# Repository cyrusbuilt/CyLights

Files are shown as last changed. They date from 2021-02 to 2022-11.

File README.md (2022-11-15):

# CyLights



IoT Integration Control Board and Firmware for remote controlled 5-outlet system.

## Synopsis

This system was designed to integrate with the [Etekcity Zap 5-Channel Wireless Outlet Switch System](https://www.etekcity.com/product/100068) and make it controllable via software.  I originally bought the Etekcity kit so that I could turn lamps on/off using the remote in my old apartment. I quickly realized it wouldn't be difficult to modify the remote so that I could integrate it into a home automation system. So this repo contains the design files for the board, sources for the firmware, and [OpenHAB](https://www.openhab.org/) integration files. CyLights uses an [ESP8266](https://www.adafruit.com/product/2471) at it's core, and basically just uses the remote that comes with the Etekcity kit as a transmitter, making the whole thing wireless (with the exception of the power supply) so you can place it anywhere that is in range of all your wireless outlets AND your WiFi router.

## Disclaimer

CyLights requires you to remove the battery and modify the remote that comes with the Etekcity kit. I am not liable for any damage you may cause to your controller (or any other hardware for that matter) should you attempt to do this.  Also, while I am currently using this system daily, it is still a work in progress and not yet production-ready and documentation is incomplete. If you are interested in this project, check back soon!

## I'm not a n00b, get on with it!

Ok, fair enough. Consider this a quick start guide then:

1) Review the schematics and BOM in the ```schematics``` folder.

2) Send the gerbers off to your preferred PCB fab house to get the boards made, then gather up the necessary components in the BOM. I also recommend 12 female dupont cables and a 12VDC @ 1.0A power supply and 2 TO-220 heat sinks (along with thermal paste).

3) Assemble the CyLights board, then remove the battery from the Etekcity remote and disassemble it (it only has 2 small phillips head screws).

4) Cut one end off each dupont cable, strip a small amount of insulation off each one and solder each lead to the inside contact of each button and one lead each to the battery terminals on the remote (guide coming soon).

5) Connect each dupont cable to the appropriate pins on pin header J2 on the CyLights board.

6) Connect 12VDC power supply to screw terminal block J1 on the CyLights board.

7) Connect the CyLights board to your computer using an FTDI cable and put the ESP8266 in program mode.

8) Build and flash the firmware to the MCU. Then place the MCU back into program mode again. Then edit the config.json file in the ```data``` folder with the appropriate values, then upload the filesystem image. Then reset the MCU and go into monitor mode so you can see the serial output.

9) If successful, you should be able to see the CyLights board boot correctly and connect to your WiFi. If you already have an MQTT broker set up on your network and you set the appropriate parameters in the config file, it should also successfully connect to the broker and publish its first status message.

10) If you already have OpenHAB setup somewhere on your network, you can copy the files in the ```openhab``` folder to their appropriate locations (and modify as needed) and you should be able to monitor and control the system from OpenHab via the "CyLights" sitemap.

Tada! At this point, if all is well then you can unplug the FTDI cable (unless you want to continue to monitor the serial output or access the built-in configuration and control menu) and mount or install the boards wherever/however you want. I personally mounted the whole thing in an ABS plastic box for the time being, but I intend to mount it in a custom panel along with a bunch of other gear once our new house is done being built.

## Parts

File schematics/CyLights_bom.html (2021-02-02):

Label | Part Type | Properties
C1 | Ceramic Capacitor | voltage 6.3V; package 100 mil [THT, multilayer]; capacitance 0.1mF
C2 | Ceramic Capacitor | voltage 6.3V; package 100 mil [THT, multilayer]; capacitance 0.1mF
C3 | Electrolytic Capacitor | voltage 6.3V; package 100 mil [THT, electrolytic]; capacitance 0.22mF
C4 | Ceramic Capacitor | voltage 6.3V; package 100 mil [THT, multilayer]; capacitance 0.47mF
C5 | Tantalum Capacitor | voltage 6.3V; package 100 mil [THT, tantalum]; capacitance 1μF
C6 | Ceramic Capacitor | voltage 6.3V; package 100 mil [THT, multilayer]; capacitance 0.1mF
Huzzah ESP8266 | Adafruit HUZZAH ESP8266 | variant variant 2; part # Adafruit #2471
IC1 | Voltage Regulator | variant variant 1; chip LM2940CT; voltage 9V; package to-220-alt
IC2 | Voltage Regulator | variant side; chip 78005; voltage 5V; package 78xxl
IC3 | MCP23017 I2C I/O Expander | variant PDIP
J1 | Screw terminal - 2 pins | pins 2; package THT; hole size 1.0mm,0.508mm; pin spacing 0.137in (3.5mm)
J2 | Generic male header - 12 pins | pins 12; form ♂ (male); row single; package THT; hole size 1.0mm,0.508mm; pin spacing 0.1in (2.54mm)
J3 | Generic male header - 6 pins | pins 6; form ♂ (male); row single; package THT; hole size 1.0mm,0.508mm; pin spacing 0.1in (2.54mm)
LED1 | Red (635nm) LED | leg yes; package 5 mm [THT]; color Red (635nm)
LED2 | Green (570nm) LED | leg yes; package 3 mm [THT]; color Green (570nm)
LED3 | Green (570nm) LED | leg yes; package 3 mm [THT]; color Green (570nm)
LED4 | Green (570nm) LED | leg yes; package 3 mm [THT]; color Green (570nm)
LED5 | Green (570nm) LED | leg yes; package 3 mm [THT]; color Green (570nm)
LED6 | Green (570nm) LED | leg yes; package 3 mm [THT]; color Green (570nm)
LED7 | Yellow (595nm) LED | leg yes; package 5 mm [THT]; color Yellow (595nm)
Part1 | Schematic Frame | project CyLights; descr CyLights IoT Control Board; rev 1.5; sheet 1/1; date 1563226096; filename CyLights.fzz
R1 | 4.7kΩ Resistor | resistance 4.7kΩ; bands 4; package THT; pin spacing 400 mil; tolerance ±5%
R2 | 150Ω Resistor | resistance 150Ω; bands 4; package THT; pin spacing 400 mil; tolerance ±5%
U1 | AQW214 | variant variant 1; chip label AQW214; pins 8; editable pin labels false; package DIP (Dual Inline) [THT]; pin spacing 300mil
U2 | AQW214 | variant variant 1; chip label AQW214; pins 8; editable pin labels false; package DIP (Dual Inline) [THT]; pin spacing 300mil
U3 | AQW214 | variant variant 1; chip label AQW214; pins 8; editable pin labels false; package DIP (Dual Inline) [THT]; pin spacing 300mil
U4 | AQW214 | variant variant 1; chip label AQW214; pins 8; editable pin labels false; package DIP (Dual Inline) [THT]; pin spacing 300mil
U5 | AQW214 | variant variant 1; chip label AQW214; pins 8; editable pin labels false; package DIP (Dual Inline) [THT]; pin spacing 300mil
Amount | Part Type | Properties
3 | Ceramic Capacitor | voltage 6.3V; package 100 mil [THT, multilayer]; capacitance 0.1mF
1 | Electrolytic Capacitor | voltage 6.3V; package 100 mil [THT, electrolytic]; capacitance 0.22mF
1 | Ceramic Capacitor | voltage 6.3V; package 100 mil [THT, multilayer]; capacitance 0.47mF
1 | Tantalum Capacitor | voltage 6.3V; package 100 mil [THT, tantalum]; capacitance 1μF
1 | Adafruit HUZZAH ESP8266 | variant variant 2; part # Adafruit #2471
1 | Voltage Regulator | variant variant 1; chip LM2940CT; voltage 9V; package to-220-alt
1 | Voltage Regulator | variant side; chip 78005; voltage 5V; package 78xxl
1 | MCP23017 I2C I/O Expander | variant PDIP
1 | Screw terminal - 2 pins | pins 2; package THT; hole size 1.0mm,0.508mm; pin spacing 0.137in (3.5mm)
1 | Generic male header - 12 pins | pins 12; form ♂ (male); row single; package THT; hole size 1.0mm,0.508mm; pin spacing 0.1in (2.54mm)
1 | Generic male header - 6 pins | pins 6; form ♂ (male); row single; package THT; hole size 1.0mm,0.508mm; pin spacing 0.1in (2.54mm)
1 | Red (635nm) LED | leg yes; package 5 mm [THT]; color Red (635nm)
5 | Green (570nm) LED | leg yes; package 3 mm [THT]; color Green (570nm)
1 | Yellow (595nm) LED | leg yes; package 5 mm [THT]; color Yellow (595nm)
1 | Schematic Frame | project CyLights; descr CyLights IoT Control Board; rev 1.5; sheet 1/1; date 1563226096; filename CyLights.fzz
1 | 4.7kΩ Resistor | resistance 4.7kΩ; bands 4; package THT; pin spacing 400 mil; tolerance ±5%
1 | 150Ω Resistor | resistance 150Ω; bands 4; package THT; pin spacing 400 mil; tolerance ±5%
5 | AQW214 | variant variant 1; chip label AQW214; pins 8; editable pin labels false; package DIP (Dual Inline) [THT]; pin spacing 300mil

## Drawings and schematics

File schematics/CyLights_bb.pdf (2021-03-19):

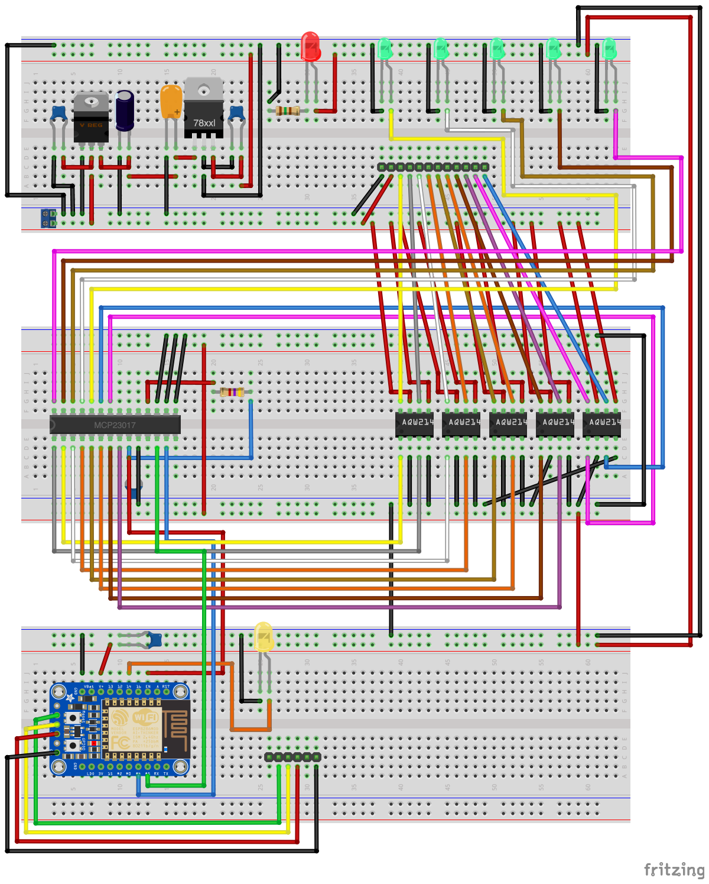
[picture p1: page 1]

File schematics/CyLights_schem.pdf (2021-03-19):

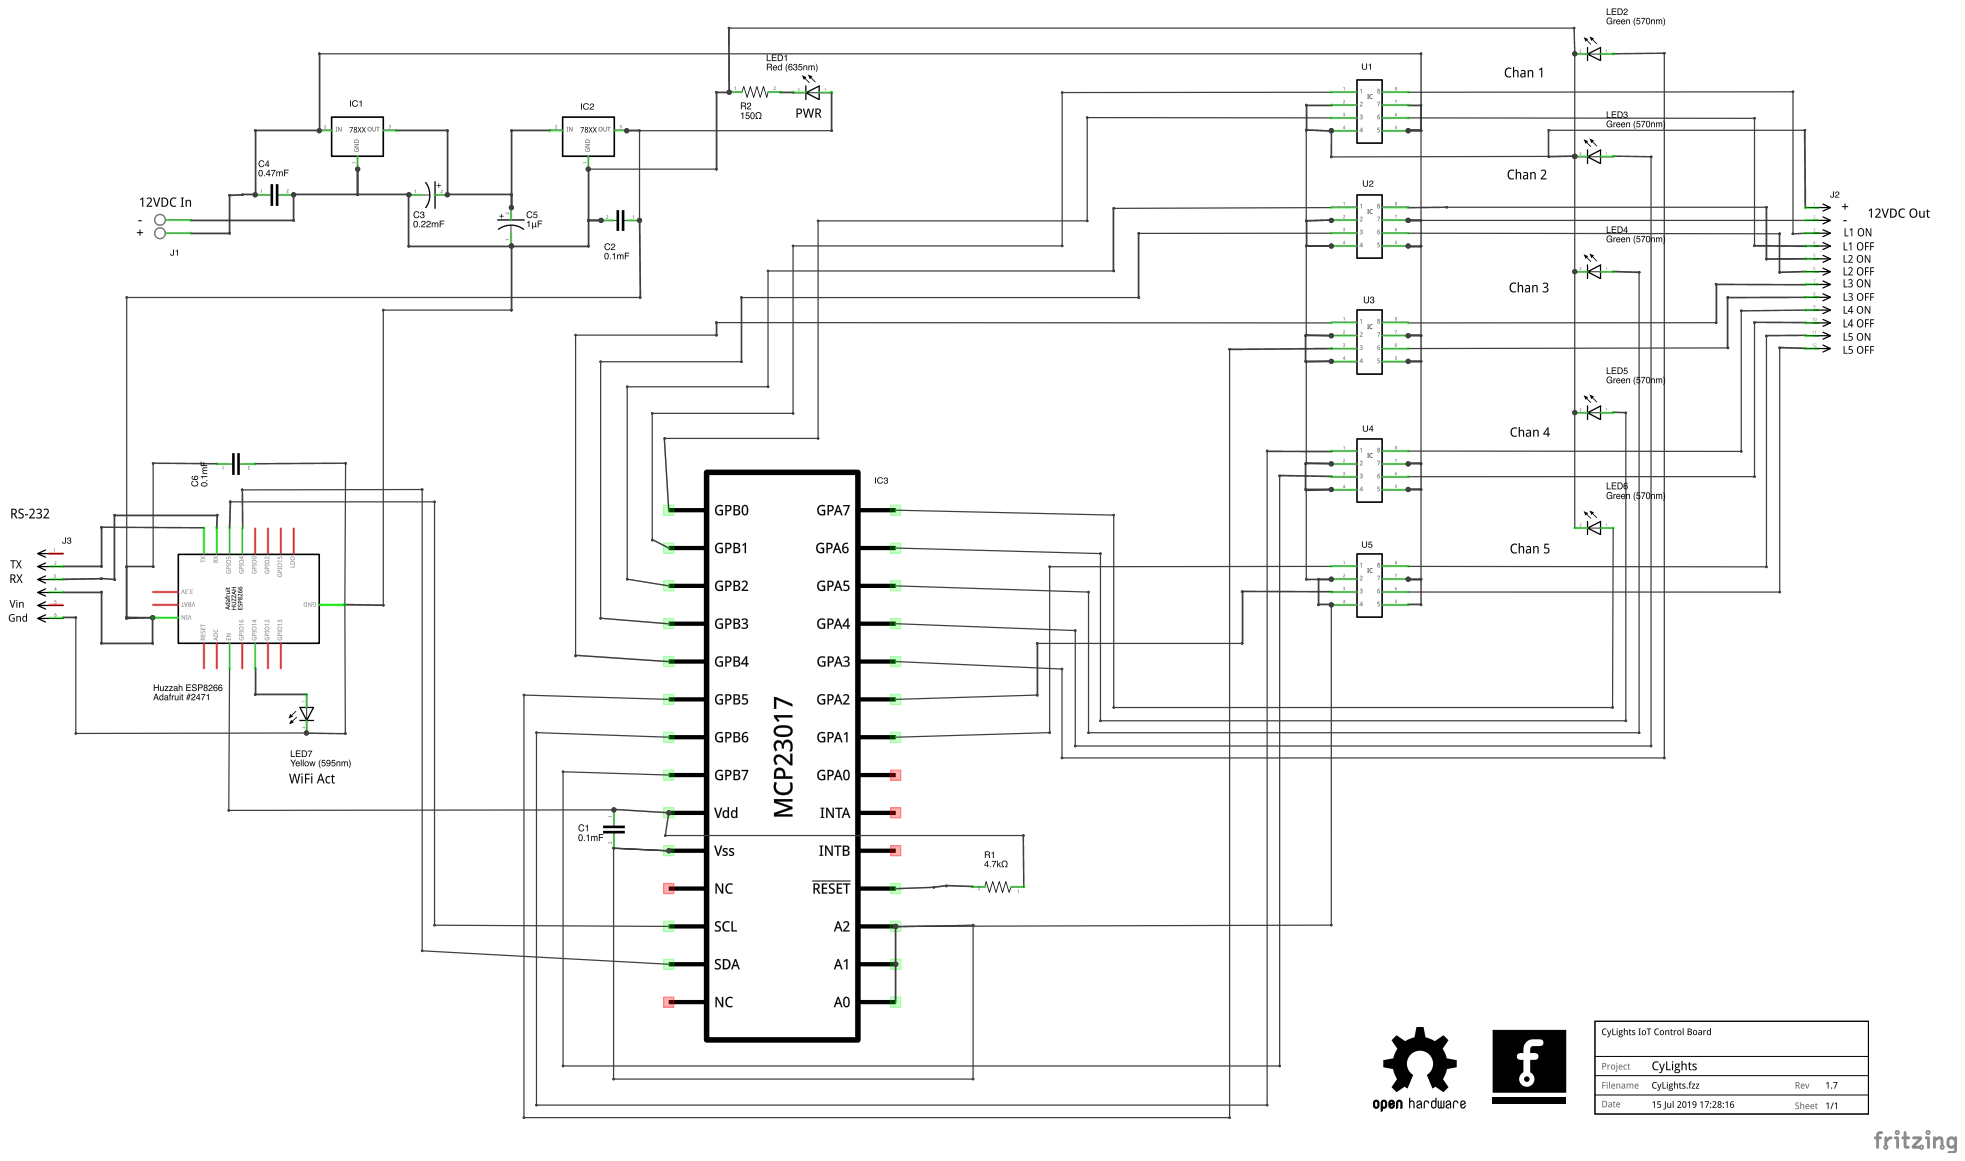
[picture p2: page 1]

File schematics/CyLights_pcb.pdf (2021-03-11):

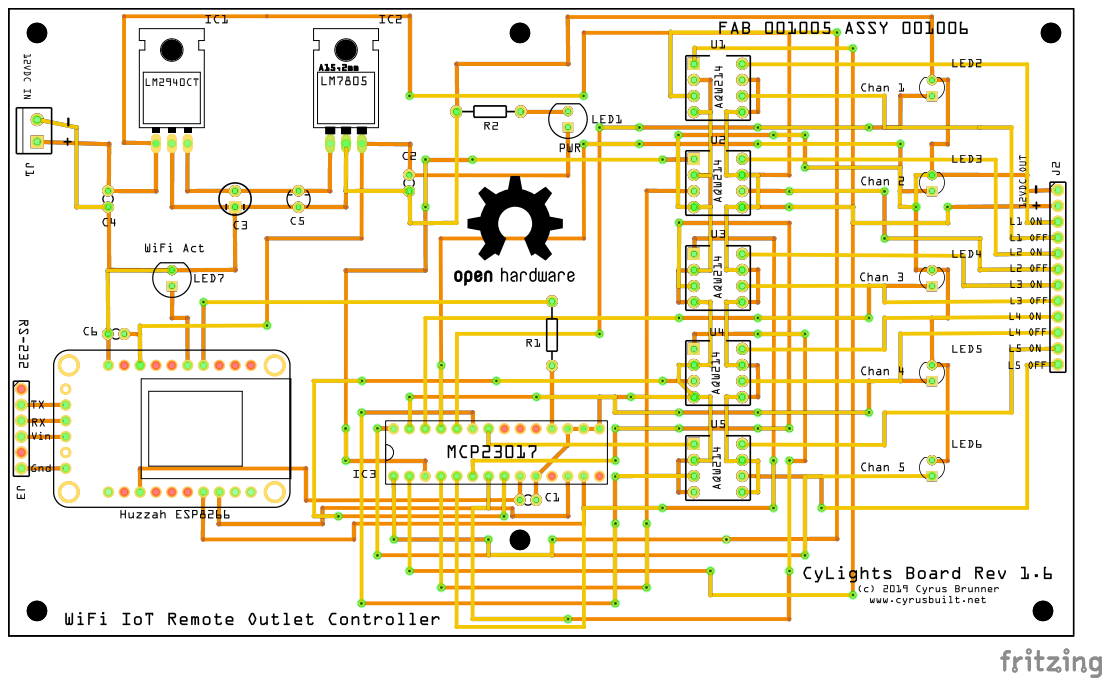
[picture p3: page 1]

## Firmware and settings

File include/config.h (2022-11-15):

#ifndef config_h
#define config_h

#include <IPAddress.h>

// Configuration
#define DEBUG                                   // Uncomment to enable additional debug info.
#define DEVICE_NAME "CYLIGHTS"                  // The device name.
#define DEVICE_CLASS "cylights"                 // The device class (used for discovery).
#define ENABLE_OTA                              // Comment this line to disable OTA updates.
#define ENABLE_MDNS                             // Comment this line to disable the MDNS.
#define DEFAULT_SSID "your_ssid_here"           // Put the SSID of your WiFi here.
#define DEFAULT_PASSWORD "your_password_here"   // Put your WiFi password here.
#define CLOCK_TIMEZONE -4                       // The timezone this device is located in. (For example, EST when observing DST = GMT-4, when not = GMT-5)
#define SERIAL_BAUD 115200                      // The BAUD rate (speed) of the serial port (console).
#define CONFIG_FILE_PATH "/config.json"         // The path to the config file in SPIFFS.
#define CHECK_WIFI_INTERVAL 60000               // How often to check WiFi status (milliseconds).
#define CHECK_MQTT_INTERVAL 120000               // How often to check connectivity to the MQTT broker.
#define CLOCK_SYNC_INTERVAL 3600000             // How often to sync the local clock with NTP (milliseconds).
#define MQTT_TOPIC_STATUS "cylights/status"     // The MQTT topic to publish status messages to.
#define MQTT_TOPIC_CONTROL "cylights/control"   // The MQTT topic to subscribe to for control messages.
#define MQTT_TOPIC_DISCOVERY "redqueen/config"  // The MQTT topic to publish discovery packets to.
#define BUTTON_PULSE_DELAY 1000                 // How long to pulse an on/off button.
#define MQTT_BROKER "your_mqtt_host_here"       // The host name or IP of the MQTT broker to connect to.
#define MQTT_PORT 1883                          // The MQTT port to connect on (default is 1883).
#ifdef ENABLE_OTA
    #include <ArduinoOTA.h>
    #define OTA_HOST_PORT 8266                     // The OTA updater port.
    #define OTA_PASSWORD "your_ota_password_here"  // The OTA updater password.
#endif
IPAddress defaultIp(192, 168, 0, 220);                 // The default static host IP.
IPAddress defaultGw(192, 168, 0, 1);                   // The default static gateway IP.
IPAddress defaultSm(255, 255, 255, 0);                 // The default static subnet mask.
IPAddress defaultDns(defaultGw);

typedef struct {
    // Network stuff
    String hostname;
    String ssid;
    String password;
    IPAddress ip;
    IPAddress gw;
    IPAddress sm;
    IPAddress dns;
    bool useDhcp;

    uint8_t clockTimezone;

    // MQTT stuff
    String mqttTopicStatus;
    String mqttTopicControl;
    String mqttTopicDiscovery;
    String mqttBroker;
    String mqttUsername;
    String mqttPassword;
    uint16_t mqttPort;

    // OTA stuff
    uint16_t otaPort;
    String otaPassword;
} config_t;

#endif

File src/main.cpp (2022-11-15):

/**
 * @file main.cpp
 * @author Chris (Cyrus) Brunner (cyrusbuilt at gmail dot com)
 * 
 * @brief CyLights Firmware
 * This is the firmware for CyLights, an IoT integration system designed to
 * be used with a modified version of the Etekcity 5-outlet remote control
 * system. CyLights is meant to essentially convert the remote control into
 * an RF transmitter peripheral which is then powered and controlled by CyLights
 * itself and can then be controlled over MQTT and can be integrated with
 * home automation systems such as OpenHab.
 * 
 * @version 1.3
 * @copyright Copyright (c) Cyrus Brunner 2022
 */

#ifndef ESP8266
    #error This firmware is only compatible with ESP8266 controllers.
#endif

#include <Arduino.h>
#include <ESP8266WiFi.h>
#include <FS.h>
#include <WiFiClient.h>
#include <Wire.h>
#include <time.h>
#include <TZ.h>
#include "config.h"
#include "Adafruit_MCP23017.h"
#include "TelemetryHelper.h"
#include "LED.h"
#include "Relay.h"
#include "PubSubClient.h"
#include "TaskScheduler.h"
#include "ResetManager.h"
#include "ESPCrashMonitor.h"
#include "ArduinoJson.h"
#include "LightController.h"
#include "Console.h"

#define VERSION "1.3"

#define PRIMARY_I2C_ADDRESS 0
#define I2C_ADDRESS_OFFSET 32

// Pin definitions
#define PIN_ACT_LED 14
#define PIN_BUS_RESET 16

// Forward declarations
void onCheckWiFi();
void onCheckMqtt();
void failSafe();
void onMqttMessage(char* topic, byte* payload, unsigned int length);
void onSyncClock();

// Global vars
#ifdef ENABLE_MDNS
    #include <ESP8266mDNS.h>
    MDNSResponder mdns;
#endif
WiFiClient wifiClient;
PubSubClient mqttClient(wifiClient);
LED actLED(PIN_ACT_LED, NULL);
Task tCheckWifi(CHECK_WIFI_INTERVAL, TASK_FOREVER, &onCheckWiFi);
Task tCheckMqtt(CHECK_MQTT_INTERVAL, TASK_FOREVER, &onCheckMqtt);
Task tSyncClock(CLOCK_SYNC_INTERVAL, TASK_FOREVER, &onSyncClock);
Scheduler taskMan;
Adafruit_MCP23017 bus;
LightController controller(&bus);
config_t config;
bool filesystemMounted = false;
bool primaryExpanderFound = false;
volatile SystemState sysState = SystemState::BOOTING;

/**
 * @brief Get the Current Time object
 * 
 * @return String 
 */
String getCurrentTime() {
    time_t now = time(nullptr);
    struct tm *timeinfo = localtime(&now);
    String result = String(asctime(timeinfo));
    result.replace("\n", "");
    return result;
}

/**
 * @brief Synchronize the local system clock via NTP. Note: This does not take DST
 * into account. Currently, you will have to adjust the CLOCK_TIMEZONE define
 * manually to account for DST when needed.
 */
void onSyncClock() {
    configTime(TZ_America_New_York, "pool.ntp.org");
    Serial.print(F("INIT: Waiting for NTP time sync..."));
    delay(500);
    while (!time(nullptr)) {
        ESPCrashMonitor.iAmAlive();
        Serial.print(F("."));
        delay(500);
    }

    Serial.println(F("DONE"));
    Serial.print(F("INFO: Current time: "));
    Serial.println(getCurrentTime());
}

/**
 * @brief Publishes the system's current state to the configured status topic.
 */
void publishSystemState() {
    if (mqttClient.connected()) {
        actLED.on();
        uint16_t freeMem = ESP.getMaxFreeBlockSize() - 512;

        DynamicJsonDocument doc(freeMem);
        doc["client_id"] = config.hostname;
        doc["systemState"] = (uint8_t)sysState;
        doc["firmwareVersion"] = VERSION;
        doc["light1State"] = (uint8_t)controller.getState((LightSelect)1);
        doc["light2State"] = (uint8_t)controller.getState((LightSelect)2);
        doc["light3State"] = (uint8_t)controller.getState((LightSelect)3);
        doc["light4State"] = (uint8_t)controller.getState((LightSelect)4);
        doc["light5State"] = (uint8_t)controller.getState((LightSelect)5);
        doc.shrinkToFit();

        String jsonStr;
        size_t len = serializeJson(doc, jsonStr);
        Serial.print(F("INFO: Publishing system state: "));
        Serial.println(jsonStr);
        if (!mqttClient.publish(config.mqttTopicStatus.c_str(), jsonStr.c_str(), len)) {
            Serial.println(F("ERROR: Failed to publish message."));
        }

        doc.clear();
        actLED.off();
    }
}

/**
 * @brief Publishes a discovery packet to the configured discovery topic.
 */
void publishDiscoveryPacket() {
    if (mqttClient.connected()) {
        actLED.on();

        DynamicJsonDocument doc(250);
        doc["name"] = config.hostname;
        doc["class"] = DEVICE_CLASS;
        doc["statusTopic"] = config.mqttTopicStatus;
        doc["controlTopic"] = config.mqttTopicControl;

        String jsonStr;
        size_t len = serializeJson(doc, jsonStr);
        Serial.print(F("INFO: Publishing discovery packet: "));
        Serial.println(jsonStr);
        if (!mqttClient.publish(config.mqttTopicStatus.c_str(), jsonStr.c_str(), len)) {
            Serial.println(F("ERROR: Failed to publish message."));
        }

        doc.clear();
        actLED.off();
    }
}

/**
 * @brief Halt-and-Catch-Fire routine. Disables the system and goes into a
 * halt state, which is essentially an infinite loop that only feeds the
 * watchdog. This method never returns.
 */
void HCF() {
    Serial.println(F("ERROR: ******* SYSTEM HALTED *******"));
    Serial.flush();
    sysState = SystemState::DISABLED;
    while (true) {
        ESPCrashMonitor.iAmAlive();
        delay(10);
    }
}

/**
 * @brief Resets the I2C I/O controller (MCP23017) by pulsing the reset pin.
 */
void resetCommBus() {
    Serial.print(F("INFO: Resetting comm bus... "));
    digitalWrite(PIN_BUS_RESET, LOW);
    delay(500);
    digitalWrite(PIN_BUS_RESET, HIGH);
    Serial.println(F("DONE"));
}

/**
 * @brief Disables the system and publishes the system's state to the
 * configured status topic, then soft-reboots the MCU.
 */
void reboot() {
    Serial.println(F("INFO: Rebooting..."));
    Serial.flush();
    delay(1000);
    sysState = SystemState::DISABLED;
    publishSystemState();
    resetCommBus();
    ResetManager.softReset();
}

/**
 * @brief Prints network information details to the serial console.
 */
void printNetworkInfo() {
    Serial.print(F("INFO: Local IP: "));
    Serial.println(WiFi.localIP());
    Serial.print(F("INFO: Gateway: "));
    Serial.println(WiFi.gatewayIP());
    Serial.print(F("INFO: Subnet mask: "));
    Serial.println(WiFi.subnetMask());
    Serial.print(F("INFO: DNS server: "));
    Serial.println(WiFi.dnsIP());
    Serial.print(F("INFO: MAC address: "));
    Serial.println(WiFi.macAddress());
    #ifdef DEBUG
    WiFi.printDiag(Serial);
    #endif
}

/**
 * @brief Scan for available networks and dump each discovered network to the
 * console.
 */
void getAvailableNetworks() {
    ESPCrashMonitor.defer();
    Serial.println(F("INFO: Scanning WiFi networks..."));
    int numNetworks = WiFi.scanNetworks();
    for (int i = 0; i < numNetworks; i++) {
        Serial.print(F("ID: "));
        Serial.print(i);
        Serial.print(F("\tNetwork name: "));
        Serial.print(WiFi.SSID(i));
        Serial.print(F("\tSignal strength:"));
        Serial.println(WiFi.RSSI(i));
    }
    Serial.println(F("----------------------------------"));
}

/**
 * @brief Stores the in-memory configuration to a JSON file stored in SPIFFS.
 * If the file does not yet exist, it will be created (see CONFIG_FILE_PATH).
 * Errors will be reported to the serial console if the filesystem is not
 * mounted or if the file could not be opened for writing. Currently only
 * stores network configuration settings (IP, WiFi, etc).
 */
void saveConfiguration() {
    Serial.print(F("INFO: Saving configuration to: "));
    Serial.print(CONFIG_FILE_PATH);
    Serial.println(F(" ... "));
    if (!filesystemMounted) {
        Serial.println(F("FAIL"));
        Serial.println(F("ERROR: Filesystem not mounted."));
        return;
    }

    File configFile = SPIFFS.open(CONFIG_FILE_PATH, "w");
    if (!configFile) {
        Serial.println(F("FAIL"));
        Serial.println(F("ERROR: Failed to open config file for writing."));
        return;
    }
    
    uint16_t freeMem = ESP.getMaxFreeBlockSize() - 512;

    DynamicJsonDocument doc(freeMem);
    doc["hostname"] = config.hostname;
    doc["useDHCP"] = config.useDhcp;
    doc["ip"] = config.ip.toString();
    doc["gateway"] = config.gw.toString();
    doc["subnetMask"] = config.sm.toString();
    doc["dnsServer"] = config.dns.toString();
    doc["wifiSSID"] = config.ssid;
    doc["wifiPassword"] = config.password;
    doc["mqttBroker"] = config.mqttBroker;
    doc["mqttPort"] = config.mqttPort;
    doc["mqttControlTopic"] = config.mqttTopicControl;
    doc["mqttStatusTopic"] = config.mqttTopicStatus;
    doc["mqttDiscoveryTopic"] = config.mqttTopicDiscovery;
    doc["mqttUsername"] = config.mqttUsername;
    doc["mqttPassword"] = config.mqttPassword;
    #ifdef ENABLE_OTA
        doc["otaPort"] = config.otaPort;
        doc["otaPassword"] = config.otaPassword;
    #endif
    doc.shrinkToFit();

    serializeJsonPretty(doc, configFile);
    doc.clear();

    configFile.flush();
    configFile.close();
    Serial.println(F("DONE"));
}

/**
 * @brief Sets the running configuration to factory defaults.
 */
void setConfigurationDefaults() {
    String chipId = String(ESP.getChipId(), HEX);
    String defHostname = String(DEVICE_NAME) + "_" + chipId;

    config.hostname = defHostname;
    config.ip = defaultIp;
    config.mqttBroker = MQTT_BROKER;
    config.mqttPassword = "";
    config.mqttPort = MQTT_PORT;
    config.mqttTopicControl = MQTT_TOPIC_CONTROL;
    config.mqttTopicStatus = MQTT_TOPIC_STATUS;
    config.mqttTopicDiscovery = MQTT_TOPIC_DISCOVERY;
    config.mqttUsername = "";
    config.password = DEFAULT_PASSWORD;
    config.sm = defaultSm;
    config.ssid = DEFAULT_SSID;
    config.useDhcp = false;
    config.clockTimezone = CLOCK_TIMEZONE;
    config.dns = defaultDns;
    config.gw = defaultGw;
    #ifdef ENABLE_OTA
        config.otaPassword = OTA_PASSWORD;
        config.otaPort = OTA_HOST_PORT;
    #endif
}

/**
 * @brief Helper method that prints the specified warning message to the
 * console.
 * 
 * @param message The message to print.
 */
void printWarningAndContinue(const __FlashStringHelper *message) {
    Serial.println();
    Serial.println(message);
    Serial.print(F("INFO: Continuing... "));
}

/**
 * @brief Loads the configuration from CONFIG_FILE_PATH into memory and uses
 * that as the running configuration. Will report errors to the serial console
 * and revert to the default configuration under the following conditions:
 * 1) The filesystem is not mounted.
 * 2) The config file does not exist in SPIFFS. In this case a new file
 * will be created and populated with the default configuration.
 * 3) The config file exists, but could not be opened for reading.
 * 4) The config file is too big ( > 1MB).
 * 5) The config file could not be deserialized to a JSON structure.
 */
void loadConfiguration() {
    memset(&config, 0, sizeof(config));

    Serial.print(F("INFO: Loading config file: "));
    Serial.print(CONFIG_FILE_PATH);
    Serial.print(F(" ... "));
    if (!filesystemMounted) {
        Serial.println(F("FAIL"));
        Serial.println(F("ERROR: Filesystem not mounted."));
        return;
    }

    if (!SPIFFS.exists(CONFIG_FILE_PATH)) {
        Serial.println(F("FAIL"));
        Serial.println(F("WARN: Config file does not exist. Creating with default config..."));
        saveConfiguration();
        return;
    }

    File configFile = SPIFFS.open(CONFIG_FILE_PATH, "r");
    if (!configFile) {
        Serial.println("FAIL");
        Serial.println(F("ERROR: Unable to open config file. Using default config."));
        return;
    }

    size_t size = configFile.size();
    uint16_t freeMem = ESP.getMaxFreeBlockSize() - 512;
    if (size > freeMem) {
        Serial.println(F("FAIL"));
        Serial.print(F("ERROR: Not enough free memory to load document. Size = "));
        Serial.print(size);
        Serial.print(F(", Free = "));
        Serial.println(freeMem);
        configFile.close();
        return;
    }

    DynamicJsonDocument doc(freeMem);
    DeserializationError error = deserializeJson(doc, configFile);
    if (error) {
        Serial.println(F("FAIL"));
        Serial.println(F("ERROR: Failed to parse config file to JSON. Using default config."));
        configFile.close();
        return;
    }

    doc.shrinkToFit();
    configFile.close();

    String chipId = String(ESP.getChipId(), HEX);
    String defHostname = String(DEVICE_NAME) + "_" + chipId;

    config.hostname = doc.containsKey("hostname") ? doc["hostname"].as<String>() : defHostname;
    config.useDhcp = doc.containsKey("isDhcp") ? doc["isDhcp"].as<bool>() : false;
    
    if (doc.containsKey("ip")) {
        if (!config.ip.fromString(doc["ip"].as<String>())) {
            printWarningAndContinue(F("WARN: Invalid IP in configuration. Falling back to factory default."));
        }
    }
    else {
        config.ip = defaultIp;
    }

    if (doc.containsKey("gateway")) {
        if (!config.gw.fromString(doc["gateway"].as<String>())) {
            printWarningAndContinue(F("WARN: Invalid gateway in configuration. Falling back to factory default."));
        }
    }
    else {
        config.gw = defaultGw;
    }

    if (doc.containsKey("subnetmask")) {
        if (!config.sm.fromString(doc["subnetmask"].as<String>())) {
            printWarningAndContinue(F("WARN: Invalid subnet mask in configuration. Falling back to factory default."));
        }
    }
    else {
        config.sm = defaultSm;
    }

    if (doc.containsKey("dns")) {
        if (!config.dns.fromString(doc["dns"].as<String>())) {
            printWarningAndContinue(F("WARN: Invalid DNS IP in configuration. Falling back to factory default."));
        }
    }
    else {
        config.dns = defaultDns;
    }

    config.ssid = doc.containsKey("wifiSSID") ? doc["wifiSSID"].as<String>() : DEFAULT_SSID;
    config.password = doc.containsKey("wifiPassword") ? doc["wifiPassword"].as<String>() : DEFAULT_PASSWORD;
    config.mqttBroker = doc.containsKey("mqttBroker") ? doc["mqttBroker"].as<String>() : MQTT_BROKER;
    config.mqttPort = doc.containsKey("mqttPort") ? doc["mqttPort"].as<int>() : MQTT_PORT;
    config.mqttTopicControl = doc.containsKey("mqttControlTopic") ? doc["mqttControlTopic"].as<String>() : MQTT_TOPIC_CONTROL;
    config.mqttTopicStatus = doc.containsKey("mqttStatusTopic") ? doc["mqttStatusTopic"].as<String>() : MQTT_TOPIC_STATUS;
    config.mqttTopicDiscovery = doc.containsKey("mqttDiscoveryTopic") ? doc["mqttDiscoveryTopic"].as<String>() : MQTT_TOPIC_DISCOVERY;
    config.mqttUsername = doc.containsKey("mqttUsername") ? doc["mqttUsername"].as<String>() : "";
    config.mqttPassword = doc.containsKey("mqttPassword") ? doc["mqttPassword"].as<String>() : "";

    #ifdef ENABLE_OTA
        config.otaPort = doc.containsKey("otaPort") ? doc["otaPort"].as<uint16_t>() : MQTT_PORT;
        config.otaPassword = doc.containsKey("otaPassword") ? doc["otaPassword"].as<String>() : OTA_PASSWORD;
    #endif

    doc.clear();
    Serial.println(F("DONE"));
}

/**
 * @brief Resume normal operation. This will resume any suspended tasks.
 */
void resumeNormal() {
    Serial.println(F("INFO: Resuming normal operation..."));
    taskMan.enableAll();
    actLED.off();
    sysState = SystemState::NORMAL;
    publishSystemState();
}

/**
 * @brief Confirms with the user that they wish to do a factory restore. If so,
 * then clears the current configuration file in SPIFFS, then reboots. Upon
 * reboot, a new config file will be generated with default values.
 */
void doFactoryRestore() {
    Serial.println();
    Serial.println(F("Are you sure you wish restore to factory default? (Y/n)?"));
    Console.waitForUserInput();
    String str = Console.getInputString();
    if (str == "Y" || str == "y") {
        Serial.print(F("INFO: Clearing current config... "));
        if (filesystemMounted) {
            if (SPIFFS.remove(CONFIG_FILE_PATH)) {
                Serial.println(F("DONE"));
                Serial.print(F("INFO: Removed file: "));
                Serial.println(CONFIG_FILE_PATH);

                Serial.print(F("INFO: Rebooting in "));
                for (uint8_t i = 5; i >= 1; i--) {
                    Serial.print(i);
                    Serial.print(F(" "));
                    delay(1000);
                }

                reboot();
            }
            else {
                Serial.println(F("FAIL"));
                Serial.println(F("ERROR: Failed to delete configuration file."));
            }
        }
        else {
            Serial.println(F("FAIL"));
            Serial.println(F("ERROR: Fileystem not mounted."));
        }
    }

    Serial.println();
}

/**
 * @brief Handles incoming system control requests. This executes the specified
 * command if intended for this system, then responds by publishing the
 * system state to the configured status topic.
 * @param command The command to execute.
 */
void handleControlRequest(ControlCommand command) {
    // When system is the "disabled" state, the only command it will accept
    // is "enable". All other commands are ignored.
    if (sysState == SystemState::DISABLED && command != ControlCommand::ENABLE) {
        // We can't process this command because we are disabled.
        Serial.print(F("WARN: Ignoring command "));
        Serial.print((uint8_t)command);
        Serial.print(F(" because the system is currently disabled."));
        return;
    }

    switch (command) {
        case ControlCommand::ALL_OFF:
            Serial.println(F("INFO: Turning all lights off."));
            controller.allLightsOff();
            break;
        case ControlCommand::ALL_ON:
            Serial.println(F("INFO: Turning all lights on."));
            controller.allLightsOn();
            break;
        case ControlCommand::DISABLE:
            Serial.println(F("WARN: Disabling system."));
            sysState = SystemState::DISABLED;
            break;
        case ControlCommand::ENABLE:
            Serial.println(F("INFO: Enabling system."));
            sysState = SystemState::NORMAL;
            break;
        case ControlCommand::LIGHT1_OFF:
            Serial.println(F("INFO: Turning light 1 off."));
            controller.setState(LightSelect::ONE, LightState::OFF);
            break;
        case ControlCommand::LIGHT1_ON:
            Serial.println(F("INFO: Turning light 1 one."));
            controller.setState(LightSelect::ONE, LightState::ON);
            break;
        case ControlCommand::LIGHT2_OFF:
            Serial.println(F("INFO: Turning light 2 off."));
            controller.setState(LightSelect::TWO, LightState::OFF);
            break;
        case ControlCommand::LIGHT2_ON:
            Serial.println(F("INFO: Turning light 2 on."));
            controller.setState(LightSelect::TWO, LightState::ON);
            break;
        case ControlCommand::LIGHT3_OFF:
            Serial.println(F("INFO: Turning light 3 off."));
            controller.setState(LightSelect::THREE, LightState::OFF);
            break;
        case ControlCommand::LIGHT3_ON:
            Serial.println(F("INFO: Turning light 3 on."));
            controller.setState(LightSelect::THREE, LightState::ON);
            break;
        case ControlCommand::LIGHT4_OFF:
            Serial.println(F("INFO: Turning light 4 off."));
            controller.setState(LightSelect::FOUR, LightState::OFF);
            break;
        case ControlCommand::LIGHT4_ON:
            Serial.println(F("INFO: Turning light 4 on."));
            controller.setState(LightSelect::FOUR, LightState::ON);
            break;
        case ControlCommand::LIGHT5_OFF:
            Serial.println(F("INFO: Turning light 5 off."));
            controller.setState(LightSelect::FIVE, LightState::OFF);
            break;
        case ControlCommand::LIGHT5_ON:
            Serial.println(F("INFO: Turning light 5 on."));
            controller.setState(LightSelect::FIVE, LightState::ON);
            break;
        case ControlCommand::REBOOT:
            reboot();
            break;
        case ControlCommand::IO_RESET:
            resetCommBus();
            break;
        case ControlCommand::REQUEST_STATUS:
            break;
        default:
            Serial.print(F("WARN: Unknown command: "));
            Serial.println((uint8_t)command);
            break;
    }

    publishSystemState();
}
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
void loop() {
    ESPCrashMonitor.iAmAlive();
    Console.checkInterrupt();
    taskMan.execute();
    #ifdef ENABLE_MDNS
        mdns.update();
    #endif
    #ifdef ENABLE_OTA
        ArduinoOTA.handle();
    #endif
    mqttClient.loop();
}

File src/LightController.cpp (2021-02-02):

#include "LightController.h"
#ifndef DEBUG
#define DEBUG
#endif

LightController::LightController(Adafruit_MCP23017 *busController) {
	this->_busController = busController;
}

LightController::~LightController() {
	delete this->_busController;
}

uint8_t LightController::getLightPinAddress(LightSelect light, LightState state) {
	uint8_t result = -1;
	switch (light) {
		case LightSelect::ONE:
			switch(state) {
				case LightState::ON:
					result = LIGHT_1_ON_RELAY;
					break;
				case LightState::OFF:
					result = LIGHT_1_OFF_RELAY;
					break;
				default:
					break;
			}
			break;
		case LightSelect::TWO:
			switch (state) {
				case LightState::ON:
					result = LIGHT_2_ON_RELAY;
					break;
				case LightState::OFF:
					result = LIGHT_2_OFF_RELAY;
					break;
				default:
					break;
			}
			break;
		case LightSelect::THREE:
			switch (state) {
				case LightState::ON:
					result = LIGHT_3_ON_RELAY;
					break;
				case LightState::OFF:
					result = LIGHT_3_OFF_RELAY;
					break;
				default:
					break;
			}
			break;
		case LightSelect::FOUR:
			switch (state) {
				case LightState::ON:
					result = LIGHT_4_ON_RELAY;
					break;
				case LightState::OFF:
					result = LIGHT_4_OFF_RELAY;
					break;
				default:
					break;
			}
			break;
		case LightSelect::FIVE:
			switch (state) {
				case LightState::ON:
					result = LIGHT_5_ON_RELAY;
					break;
				case LightState::OFF:
					result = LIGHT_5_OFF_RELAY;
					break;
			}
			break;
		default:
			break;
	}

	return result;
}

uint8_t LightController::getLedAddress(LightSelect light) {
	uint8_t result = -1;
	switch (light) {
		case LightSelect::ONE:
			result = CHAN_1_LED;
			break;
		case LightSelect::TWO:
			result = CHAN_2_LED;
			break;
		case LightSelect::THREE:
			result = CHAN_3_LED;
			break;
		case LightSelect::FOUR:
			result = CHAN_4_LED;
			break;
		case LightSelect::FIVE:
			result = CHAN_5_LED;
			break;
	}

	return result;
}

bool LightController::detect() {
	uint8_t address = this->getLightPinAddress(LightSelect::ONE, LightState::ON);
	this->_busController->pinMode(address, INPUT);
	this->_busController->pullUp(address, LOW);
	return this->_busController->digitalRead(address) == LOW;
}

void LightController::init() {
	for (uint8_t i = 1; i <= 5; i++) {
		uint8_t relayOnAddress = this->getLightPinAddress((LightSelect)i, LightState::ON);
		this->_busController->pinMode(relayOnAddress, OUTPUT);
		this->_busController->digitalWrite(relayOnAddress, LOW);

		uint8_t relayOffAddress = this->getLightPinAddress((LightSelect)i, LightState::OFF);
		this->_busController->pinMode(relayOffAddress, OUTPUT);
		this->_busController->digitalWrite(relayOffAddress, LOW);

		uint8_t ledAddress = this->getLedAddress((LightSelect)i);
		this->_busController->pinMode(ledAddress, OUTPUT);
		this->_busController->digitalWrite(ledAddress, LOW);
	}
}

LightState LightController::getState(LightSelect light) {
	uint8_t ledAddress = this->getLedAddress(light);
	LightState state = (LightState)this->_busController->digitalRead(ledAddress);
	#ifdef DEBUG
	Serial.println(F("DEBUG: Getting light state."));
	Serial.print(F("DEBUG: LED address: "));
	Serial.println(ledAddress);
	Serial.print(F("DEBUG: LED state: "));
	Serial.println(state == LightState::ON ? F("ON") : F("OFF"));
	#endif
	return state;
}

void LightController::setState(LightSelect light, LightState state) {
	#ifdef DEBUG
	Serial.print(F("DEBUG: Requested light: "));
	Serial.println((uint8_t)light);
	Serial.print(F("DEBUG: Requested state: "));
	Serial.println((uint8_t)state);
	#endif
	if (this->getState(light) != state) {
		#ifdef DEBUG
		Serial.println(F("DEBUG: State changing."));
		#endif
		uint8_t lightPinAddress = this->getLightPinAddress(light, state);
		#ifdef DEBUG
		Serial.print(F("DEBUG: Light pin address: "));
		Serial.println(lightPinAddress);
		Serial.println(F("DEBUG: Writing pin state: HIGH"));
		#endif
		this->_busController->digitalWrite(lightPinAddress, HIGH);

		uint8_t ledAddress = this->getLedAddress(light);
		#ifdef DEBUG
		Serial.print(F("DEBUG: LED address: "));
		Serial.println(ledAddress);
		Serial.print(F("DEBUG: Turning LED "));
		Serial.println(state == LightState::ON ? "ON" : "OFF");
		#endif
		this->_busController->digitalWrite(ledAddress, state == LightState::ON ? HIGH : LOW);
		
		delay(1500);
		#ifdef DEBUG
		Serial.println(F("DEBUG: Writing pin state: LOW"));
		#endif
		this->_busController->digitalWrite(lightPinAddress, LOW);
	}
}

bool LightController::isOn(LightSelect light) {
	return this->getState(light) == LightState::ON;
}

bool LightController::isOff(LightSelect light) {
	return this->getState(light) == LightState::OFF;
}

void LightController::turnOn(LightSelect light) {
	this->setState(light, LightState::ON);
}

void LightController::turnOff(LightSelect light) {
	this->setState(light, LightState::OFF);
}

void LightController::allLightsOn() {
	for (uint8_t i = 1; i <= 5; i++) {
		this->turnOn((LightSelect)i);
	}
}

void LightController::allLightsOff() {
	for (uint8_t i = 1; i <= 5; i++) {
		this->turnOff((LightSelect)i);
	}
}

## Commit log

2019-08-06 Initial code commit
    [CyLights.fzz]
2019-10-29 Updating board design and OH2 integration
    [CyLights.fzz]
2019-11-13 Fix design problems with power input
    Also add gerber export
    [CyLights.fzz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]
2019-11-19 Encrypt MQTT comms and fix config
    [config.h, main.cpp]
2020-12-12 Massive overhaul in design and code
    [CyLights.fzz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]
2020-12-16 Design fixes
    [CyLights.fzz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]
2020-12-29 PCB design fixes. Adding timer support to OH.
    [CyLights.fzz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]
2021-02-01 Several changes to the hardware design and FW fix
    [CyLights.fzz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]
2021-02-02 Adding I/O reset and clear config values
    [main.cpp]
2021-02-16 Fix time displays and update readme
    [main.cpp]
2021-03-11 Fix missing ground for bus control
    [CyLights.fzz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]
2021-03-19 Fix external reset line
    [CyLights.fzz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]
2022-07-05 Minor schematic fix and fix openhab rules for OH3
    [CyLights.fzz]
